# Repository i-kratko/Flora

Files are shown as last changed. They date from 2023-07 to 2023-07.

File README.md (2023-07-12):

# Flora
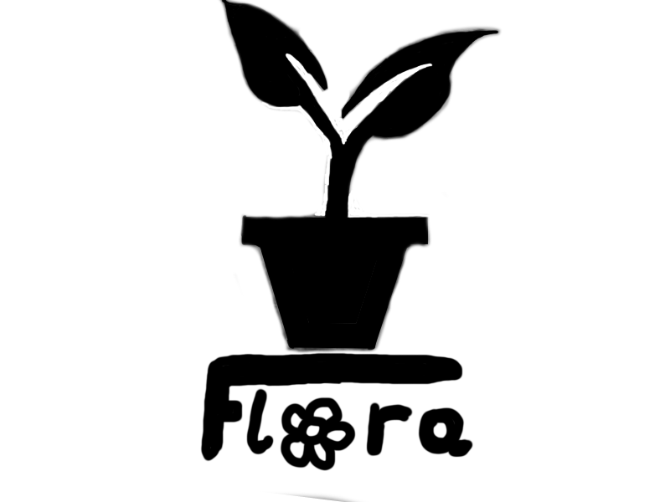
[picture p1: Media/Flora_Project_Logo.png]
Logo


Flora is an IoT project developed during my internship in Smartcom  AD. It is a plant monitoring system that keeps track of parameters such as air humidity and soil Bulgariamoisture and displays information on a Grafana dashboard.

# Блок схема

# Блок схема код

# Принципна електрическа схема
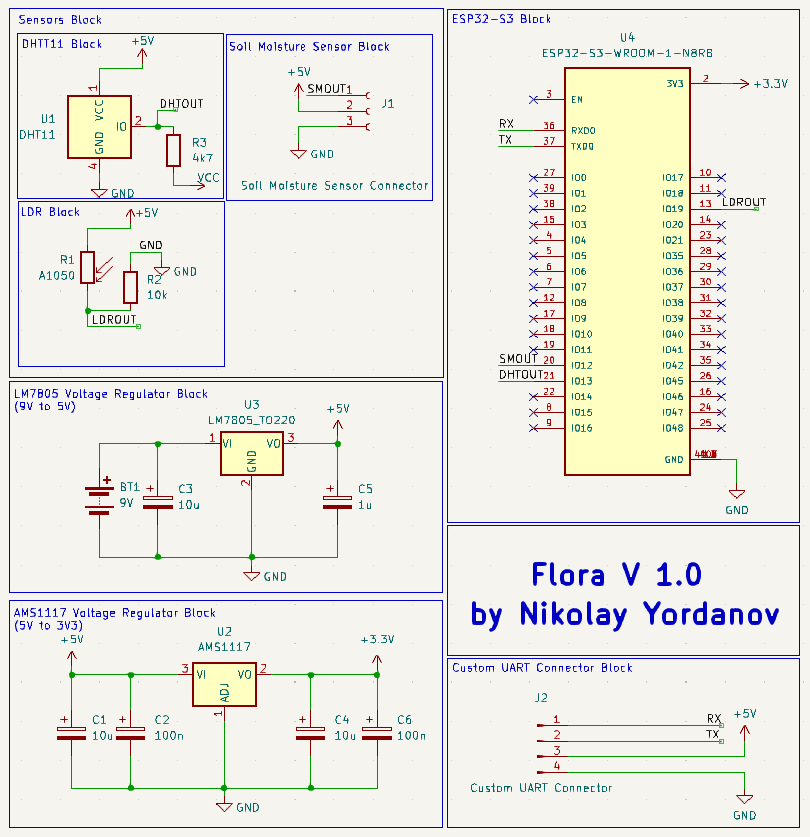
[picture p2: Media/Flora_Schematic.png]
Electrircal scheme


# Дизайн на платката
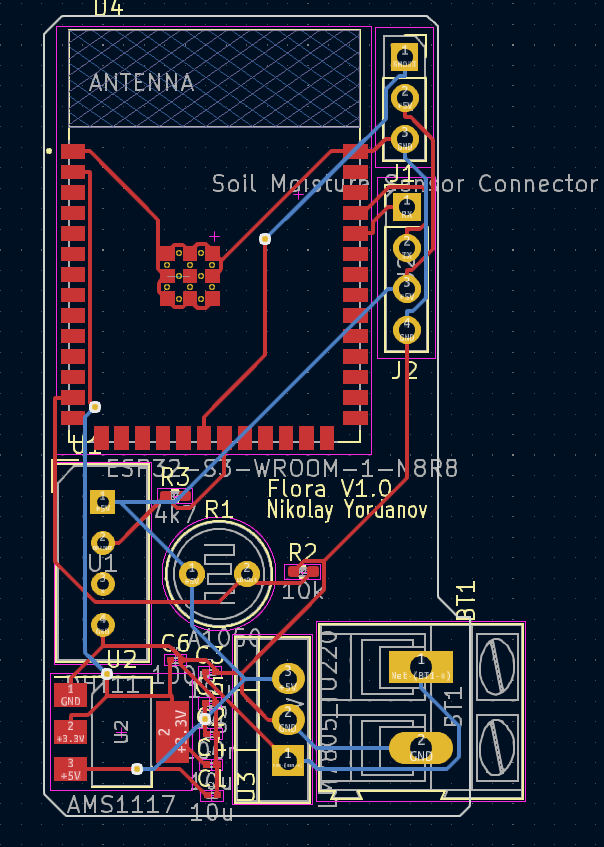
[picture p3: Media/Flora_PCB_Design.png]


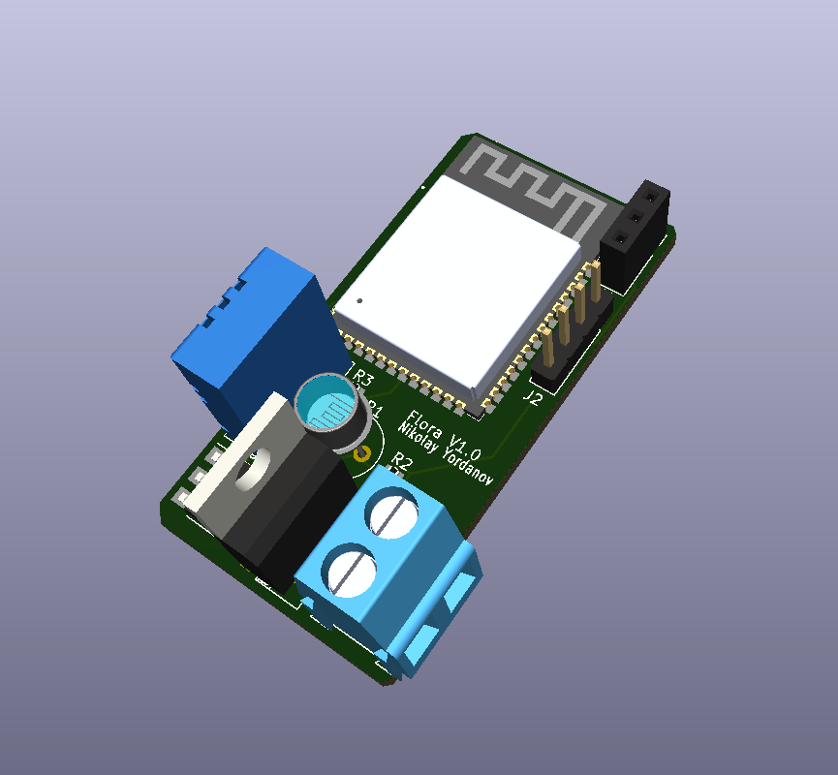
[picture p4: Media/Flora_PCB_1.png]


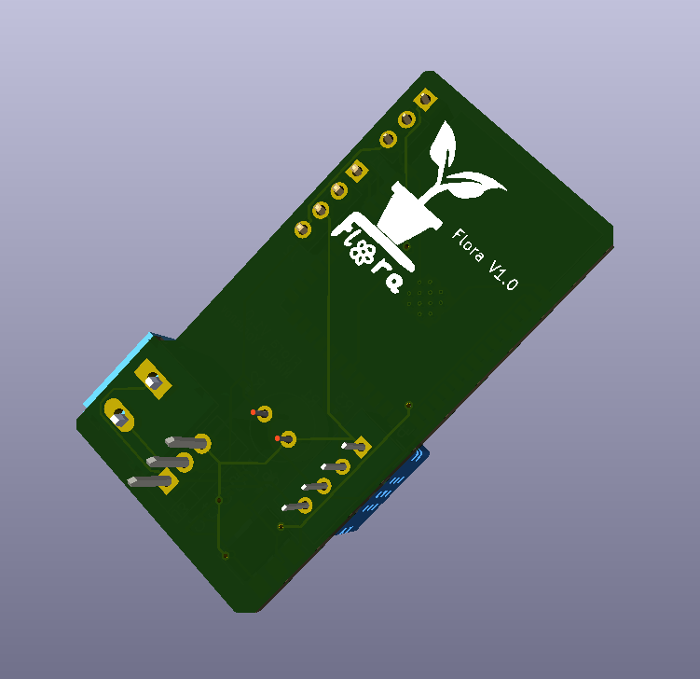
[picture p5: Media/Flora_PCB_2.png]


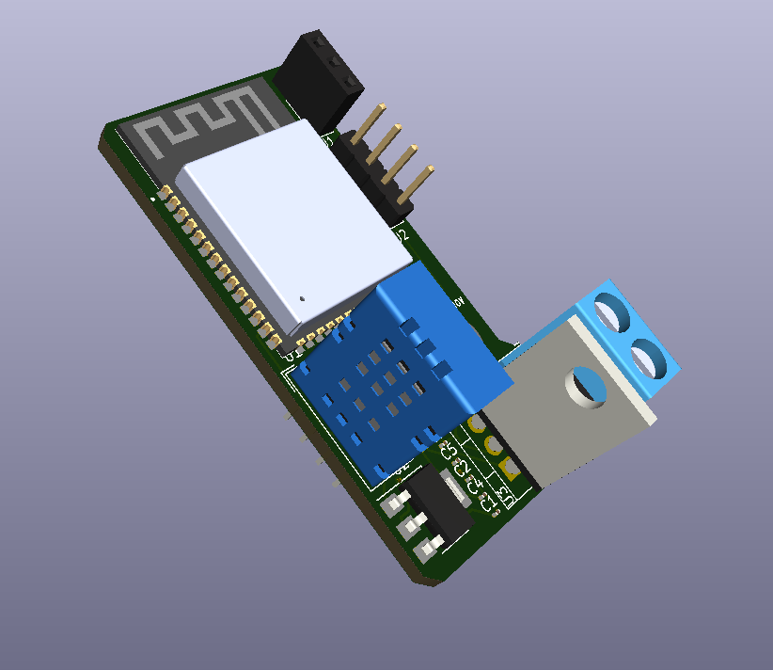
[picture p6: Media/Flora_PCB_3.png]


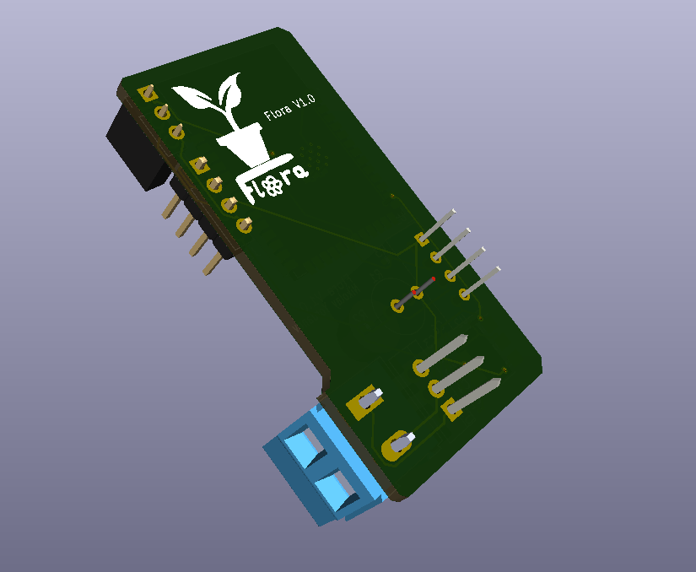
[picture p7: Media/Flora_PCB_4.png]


# Документация

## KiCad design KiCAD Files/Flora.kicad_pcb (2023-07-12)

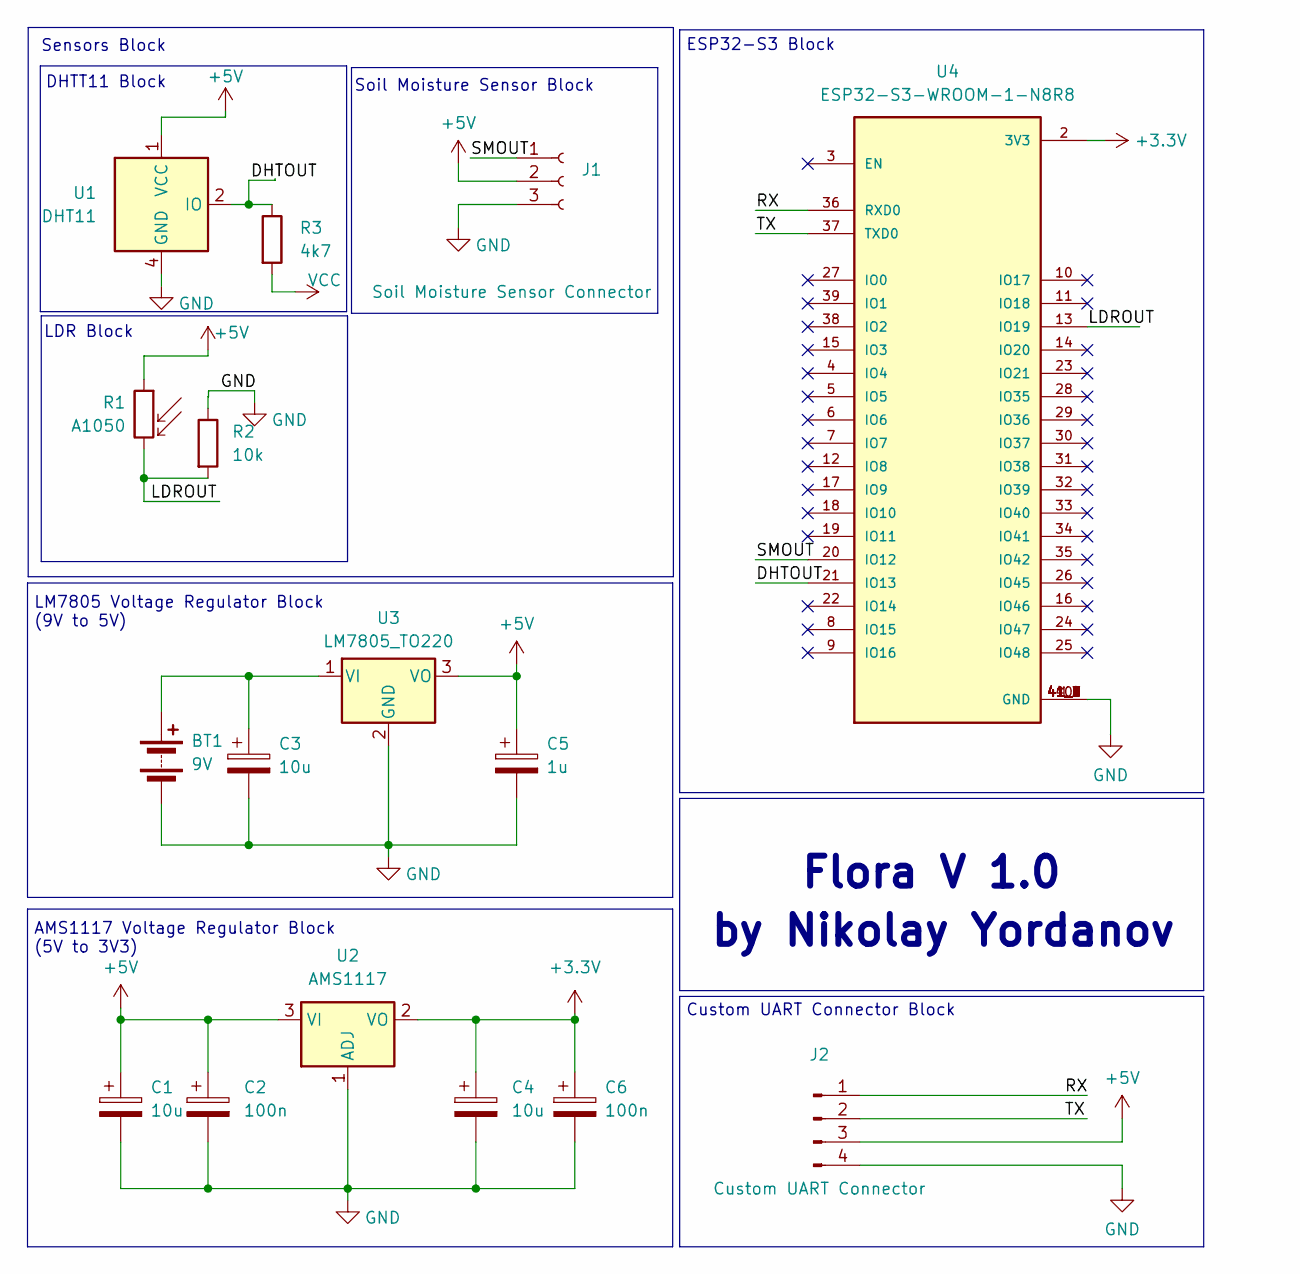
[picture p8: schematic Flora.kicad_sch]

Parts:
BT1: 9V; TerminalBlock_Altech_AK300-2_P5.00mm
C1, C3, C4: 10u; C_0201_0603Metric
C2, C6: 100n; C_0201_0603Metric
C5: 1u; C_0201_0603Metric
J1: Soil Moisture Sensor Connector; PinSocket_1x03_P2.54mm_Vertical
J2: Custom UART Connector; PinHeader_1x04_P2.54mm_Vertical
R1: A1050; R_LDR_D6.4mm_P3.4mm_Vertical
R2: 10k; R_0402_1005Metric_Pad0.72x0.64mm_HandSolder
R3: 4k7; R_0402_1005Metric_Pad0.72x0.64mm_HandSolder
U1: DHT11; Aosong_DHT11_5.5x12.0_P2.54mm
U2: AMS1117; SOT-223-3_TabPin2
U3: LM7805_TO220; TO-220-3_Vertical
U4: ESP32-S3-WROOM-1-N8R8; XCVR_ESP32S3WROOM1N8R8

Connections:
+3.3V: C4.1, C6.1, U2.2 (VO), U4.2 (3V3)
+5V: C1.1, C2.1, C5.1, J1.2, J2.3, R1.1, U1.1 (VCC), U2.3 (VI), U3.3 (VO)
/DHTOUT: R3.1, U1.2 (IO), U4.21 (IO13)
/LDROUT: R1.2, R2.2, U4.13 (IO19)
/RX: J2.1, U4.36 (RXD0)
/SMOUT: J1.1, U4.20 (IO12)
/TX: J2.2, U4.37 (TXD0)
GND: BT1.2 (-), C1.2, C2.2, C3.2, C4.2, C5.2, C6.2, J1.3, J2.4, R2.1, U1.4 (GND), U2.1 (ADJ), U3.2 (GND), U4.1 (GND), U4.40 (GND), U4.41_1 (GND), U4.41_2 (GND), U4.41_3 (GND), U4.41_4 (GND), U4.41_5 (GND), U4.41_6 (GND), U4.41_7 (GND), U4.41_8 (GND), U4.41_9 (GND)
unnamed: BT1.1 (+), C3.1, U3.1 (VI)
VCC: R3.2

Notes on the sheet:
LDR Block
Sensors Block
Flora V 1.0
Custom UART Connector Block
ESP32-S3 Block
DHTT11 Block
by Nikolay Yordanov
Soil Moisture Sensor Block
AMS1117 Voltage Regulator Block (5V to 3V3)
LM7805 Voltage Regulator Block (9V to 5V)

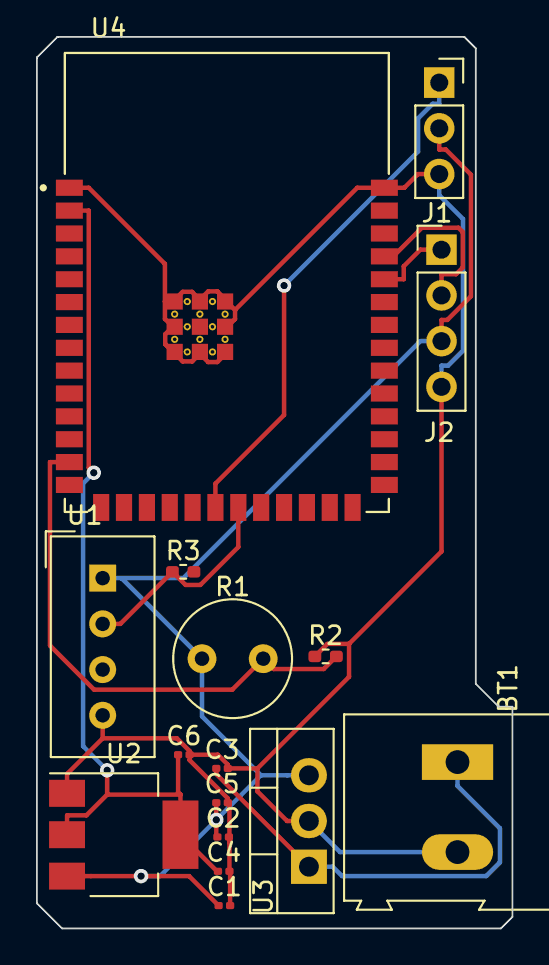
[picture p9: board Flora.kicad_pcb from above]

Board: 2 copper layers, 26.4 x 49.5 mm, 16 parts (0 on the bottom side), 9 nets.

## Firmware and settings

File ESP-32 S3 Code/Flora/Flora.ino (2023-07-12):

//library needed for the DHT11 sensor
#include <DFRobot_DHT11.h>
//library needed for Wi-Fi connection
#include <WiFi.h>
//libraries needed for the MQTT broker
#include <PubSubClient.h>
#include <WiFiClientSecure.h>

//variables needed for establishing the Wi-Fi connection
const char *SSID = "ssid";
const char *PWD = "pass";

//variables needed for the LDR
#define LDRpin 19
int lightIntensity = 0;

//variables needed for the DHT11 sensor
DFRobot_DHT11 DHT;
#define DHT_PIN 13
int temperature = 0;
int humidity = 0;

//variables needed for the soil moisture sensor
#define SOIL_PIN 12
int soilMoisture = 0;

// MQTT client
const char* mqtt_server = "mqtt server"; // replace with your broker url
const char* mqtt_username = "usr"; // replace with your Credential
const char* mqtt_password = "pass";
const int mqtt_port = 8883;

WiFiClientSecure espClient;  
PubSubClient client(espClient);
unsigned long lastMsg = 0;
#define MSG_BUFFER_SIZE  (50)
char msg[MSG_BUFFER_SIZE];

//deep sleep time (in minutes)
#define DEEP_SLEEP_TIME 1

static const char *root_ca PROGMEM = R"EOF(
-----BEGIN CERTIFICATE-----

-----END CERTIFICATE-----
)EOF";

String topic;
String messageTemp;
String message;
void callback(char* topic, byte* payload, unsigned int length) {
  String incommingMessage = "";
  for (int i = 0; i < length; i++) incommingMessage+=(char)payload[i];
  Serial.println("Message arrived ["+String(topic)+"]"+incommingMessage);
  messageTemp = topic;
  Serial.print(messageTemp);
  //==============MESSAGE RECEPTION HERE (Uncomment to edit)====================
  /* if (messageTemp == "MESSAGE INPUT"){
    YOUR VARIABLE = incommingMessage.to**WHAT YOU NEED**();
  }*/
}



//custom function for putting the esp to sleep
void goToSleep() {
  Serial.println("Honk mimimimimi");
  //set a timer for waking up the device after one minute
  esp_sleep_enable_timer_wakeup(DEEP_SLEEP_TIME * 60 * 1000000);
  //start the deep sleep mode

  esp_deep_sleep_start();
}

//custom function for connecting to the Wi-Fi network
void connectToWiFi() {
  Serial.print("Connectig to ");
 
  WiFi.begin(SSID, PWD);
  Serial.println(SSID);
  while (WiFi.status() != WL_CONNECTED) {
    Serial.print(".");
    delay(500);
  }
  Serial.print("Connected.");
}

//custom function for connecting to the MQTT broker
void reconnect() {
  // Loop until we're reconnected
  while (!client.connected()) {
    Serial.print("Attempting MQTT connection...");
    String clientId = "ESP8266Client- ";   // Create a random client ID
    clientId += String(random(0xffff), HEX);
    // Attempt to connect
    if (client.connect(clientId.c_str(), mqtt_username, mqtt_password)) {
      Serial.println("connected");

      //SUBSCRIBE TO TOPIC HERE

     // client.subscribe("SUBSCRIBE NAME");

    } else {
      Serial.print("failed, rc=");
      Serial.print(client.state());
      Serial.println(" try again in 5 seconds");   // Wait 5 seconds before retrying
      delay(5000);
    }
  }
}

void setup() {
  pinMode(LDRpin, INPUT);
  char* data = "";
  Serial.begin(9600);

  connectToWiFi();

  //TAKING MEASUREMENTS FROM THE SENSORS

  //reading the ldr values
  lightIntensity = analogRead(LDRpin);
  lightIntensity = map(lightIntensity, 0, 4095, 100, 0);
  Serial.print("Light Intensity = ");
  Serial.println(lightIntensity);

  //reading the dht11 values
  DHT.read(DHT_PIN);
  temperature = DHT.temperature;
  humidity = DHT.humidity;
  Serial.print("Temperature = ");
  Serial.println(temperature);
  Serial.print("Humidity = ");
  Serial.println(humidity);

  //reading the soil moisture sensor
  soilMoisture = analogRead(SOIL_PIN);
  Serial.print("Soil Moisture = ");
  Serial.println(soilMoisture);

  //SENDING DATA
  while (!Serial) delay(1);
  espClient.setCACert(root_ca);
  client.setServer(mqtt_server, mqtt_port);
  client.setCallback(callback);

  if (!client.connected()) reconnect();

  publishMessage("/plant/temperature",String(temperature),true);
  publishMessage("/plant/humidity",String(humidity),true);
  publishMessage("/plant/light_intensity",String(lightIntensity),true);
  publishMessage("/plant/soil_moisture",String(soilMoisture),true);

  goToSleep();

}

void loop() {
  
}

void publishMessage(const char* topic, String payload , boolean retained){
  if (client.publish(topic, payload.c_str(), true))
      Serial.println("Message publised ["+String(topic)+"]: "+payload);
}

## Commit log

2023-07-11 Added KiCAD Project Files
    [Flora.kicad_pcb, Flora.kicad_sch]
2023-07-12 Add Folder
    [Flora.kicad_pcb, Flora.kicad_sch]
2023-07-12 Added code
    [Flora.kicad_pcb, Flora.kicad_sch]
